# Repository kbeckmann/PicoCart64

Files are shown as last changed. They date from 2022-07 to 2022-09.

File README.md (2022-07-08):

# PicoCart64

Nintendo 64 flash cart using a Raspberry Pi RP2040

Join the Discord server to participate in the discussion and development of this project.

Join the Discord! (https://discord.gg/2Gb3jWqqja)

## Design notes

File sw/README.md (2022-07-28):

To build and flash with a j-link:

```bash

# First of all, don't forget to update submodules
git submodule update --init

# If you have more than 2MB flash, you need to change the SDK file src/rp2_common/pico_standard_link/memmap_copy_to_ram.ld (for now!):
# Change to: `FLASH(rx) : ORIGIN = 0x10000000, LENGTH = 16384k`

cd sw

# Load a rom into sw/picocart64/rom.h
# `--compress` will compress the rom with a simple compression scheme.
./scripts/load_rom.py --compress my_rom.z64

mkdir build
cd build

# Configure cmake. To use NTSC, set -DREGION=NTSC
# If you have more than 2MB flash, you need to change the flash size by adding -DFLASH_SIZE_MB={one of 2,4,8,16} here.

cmake -DREGION=PAL ..

# Build
make

# You can now flash it by holding down the BOOT button and resetting the device, then mounting the usb mass storage device, then copy the file picocart64/picocart64.uf2 to the mounted path and run `sync`.

# Alternatively, you can use openocd with a J-Link:

# Requires https://github.com/raspberrypi/openocd
# AUR package if you're on archlinux: https://aur.archlinux.org/packages/openocd-raspberrypi-git
openocd -f interface/jlink.cfg -c "transport select swd; adapter_khz 1000" -f target/rp2040.cfg -c "program ./picocart64/picocart64.elf verify reset exit"

# Note! You *have* to power reset the pico after flashing it with a jlink, otherwise multicore doesn't work properly.
# Alternatively, attach a debugger, `mon reset halt`, `c`, does the trick as well. It seems that openocd's `reset run` doesn't work properly.

```

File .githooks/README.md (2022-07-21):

# .githooks

To install the git hooks, please run `git config core.hooksPath .githooks` from the root of the repository.

### `pre-commit`

Executes `./sw/scripts/indent.sh -c` before a commit is made. If indentation was fixed, this will be changed in your working copy, i.e. you have to manually review and stage the changes before committing again.

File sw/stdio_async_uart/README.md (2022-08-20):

# stdio_async_uart

This is a simple interrupt based asynchronous UART TX module that works as a drop-in replacement for stdio_uart.

It uses a ringbuffer to queue up data that is to be transmitted, and starts by sending one byte.

When the byte has been transmitted, an interrupt is fired, and the next one is sent, until the tail of the ringbuffer has caught up with the head.

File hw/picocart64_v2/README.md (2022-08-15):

# PicoCart64 v2.0

:exclamation: Do not produce PCBs based on this yet, boards are untested! :exclamation:

## Errata

### v2.0
- Less than ideal VBus' routing on Inner Layer 1. The power routing should work and passes DRC, but could be better.

## Changelog

### v2.1-unreleased
- Improved power routing for VBus'

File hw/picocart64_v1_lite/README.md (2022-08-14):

# PicoCart64-lite v1.2

## Errata

### v1.3
- None so far

#### v1.2
- None so far

### v1.1
- None so far

### v1.0
- Bad power routing, thin trace goes to N64_VCC

## Changelog

### v1.3
- Added JP1, a solder bridge to make it possible to use the WeAct RP2040 third party Pico board

### v1.2
- Improved routing a lot, removed many vias
- Added more ground stitching vias
- Functionally equivalent to v1.1 and v1.0

### v1.1

- Improved power routing to N64_VCC

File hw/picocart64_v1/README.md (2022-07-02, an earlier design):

# PicoCart64 v1.0 (full)

## Errata

### v1.0
- Silk screen labels for JP1 - JP4 are in the incorrect order. It goes from bottom to top but should go the other way, i.e. correct mapping is:
  - JP1=S_DAT
  - JP2=SI_CLK
  - JP3=EEP_SDAT
  - JP4=NMI
- The signal EEP_SDAT does not exist, i.e. JP3 is unconnected.
- Pin 44 (INT/interrupt pin) is not broken out. This can be fixed with a bodge wire from pin 44 to JP3 (since EEP_SDAT is not a connected net). Pin 44 is on the top layer which is convenient.

## Changelog

### v1.1

- Connected pin 44 to JP3 (was unconnected earlier, see errata).
- Fixed silkscreen:
  - JP1=S_DAT
  - JP2=SI_CLK
  - JP3=INT
  - JP4=NMI
- Added more ground stitching vias to improve the ground plane.
- Improved routing, removed some vias

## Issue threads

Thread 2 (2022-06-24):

Investigate booting flashless RP2040 from second RP2040 over SSI/XIP -> PIO

kbeckmann, 2022-06-24:
Investigate if it's possible and practical to let one RP2040 (pico1) boot from a second RP2040 (pico2) by connecting the Flash pins to the gpios of the second.

Might need to use PIO to emulate flash in the second RP2040.

Will probably need to lower the flash speed configuration

Implementation idea:

pico2 loads the image it wants to emulate into RAM first.
pico2 sets up PIO to quickly serve QSPI read requests.
Could borrow code/ideas from the PicoCart64 code.

swetland, 2022-07-05:
Luke Wren mentioned (in a twitter conversation) that the bootrom's download of boot2 (256 byte secondary loader) is done at 1MHz and believes even a bit-banging solution should be workable.

Rather than trying to emulate QSPI modes or faster transports, my thinking was to just write a custom boot2 that would use SPI to pull an image into SRAM and jump to it.

For my use cases (using the 2nd RP2040 as an IO expander, etc), running a fixed image that is loaded at boot and fits inside the (generous) 264KB of onboard SRAM would be plenty sufficient.

At 8MHz and using large transfers, SPI download of a 128KB image would probably take under 150ms. (131ms if there were no overhead between transfers and all data were sent back to back)

kbeckmann, 2022-07-05:
Another approach which was discussed in our discord was to physically share one flash chip between the two RP2040 - even less work!

The reset/run pin of MCU1 is pulled low with a resistor, and is also connected to MCU0.

MCU0 boots and loads its program into SRAM. It reads the GPIO connected to MCU1's reset pin and sees a '0' - this lets it know that it is MCU0.

MCU0 now enables the GPIO, letting MCU1 boot. When MCU1 has booted and loaded its program into SRAM, it reads the same GPIO pin, but we make sure to connect it to a net that is pulled high in idle - now it knows it is MCU1.

kbeckmann, 2022-07-16:
We have to verify the following:

We probably need to configure the CS line to be open drain and enable a pull-up. Otherwise, when the other rp2040 is idling, it will keep CS=1 which will interfere when the first pico wants to read from the flash.
If that's not possible (because of bootrom etc), the boot sequence probably needs to be like this:

Pico1 boots normally, copies its program to RAM
Pico1 disables its SSI interface, ensuring that CS line becomes high impedance / disable output
Pico1 pulls Pico2_RUN low, allowing Pico2 to boot
Pico2 can now assert FLASH_CS high or low without any issue.
Pico2 disables its SSI interface

FLASH_CS is now allowed to be asserted by either Pico, high or low.

kbeckmann, 2022-07-24:
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

Proof of concept works!

```c

/**
 * SPDX-License-Identifier: BSD-2-Clause
 *
 * Copyright (c) 2022 Konrad Beckmann
 */

#include <stdio.h>
#include "pico/stdlib.h"
#include "hardware/structs/ssi.h"
#include "hardware/structs/ioqspi.h"

int main(void)
{
	int count = 0;

	// GPIO 2 is connected from Pico 0 to the RUN pin of Pico 1
	gpio_init(2);
	gpio_set_dir(2, GPIO_IN);

	// GPIO 25 / LED is a slow signal to show if we are running
	gpio_init(25);
	gpio_set_dir(25, GPIO_OUT);

	int pico_id = gpio_get(2) + 1;
	stdio_init_all();

	sleep_ms(1000);

	// Turn off SSI
	ssi_hw->ssienr = 0;

	// Set all QSPI IOs high impedance (disable OE)
	for (int i = 0; i < 6; i++) {
		ioqspi_hw->io[i].ctrl = (ioqspi_hw->io[i].ctrl & (~IO_QSPI_GPIO_QSPI_SCLK_CTRL_OEOVER_BITS) |
								(IO_QSPI_GPIO_QSPI_SCLK_CTRL_OEOVER_VALUE_DISABLE << IO_QSPI_GPIO_QSPI_SCLK_CTRL_OEOVER_LSB)	);
	}

	sleep_ms(1000);

	if (pico_id == 1) {
		// I am Pico 1, let Pico 2 boot
		gpio_set_dir(2, GPIO_OUT);
		gpio_put(2, 1); // GPIO2 = HIGH
	}

	while (true) {
		count++;
		printf("Hello, world! I am Pico %d -- %d\n", pico_id, count);
		gpio_put(25, !!(count & 1)); // GPIO25 = toggle LED slowly
		sleep_ms(1000);
	}
	return 0;
}

```

Closed 2022-07-24.

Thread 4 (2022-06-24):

Implement ESP32-C3 firmware update

kbeckmann, 2022-06-24:
Write/port code that updates the ESP32-C3 WiFi module over UART and toggles the boot/reset pins, from an rp2040.

See https://github.com/espressif/esp-serial-flasher

kbeckmann, 2022-06-29:
After reviewing the third v2 concept, using SPI for both communication and firmware update seems to be the way to go (same pins and more reliable probably).

kbeckmann, 2022-08-04:
Connect wires to the module so that:
GPIO2 has a pull-up
GPIO8 has a pull-up
GPIO9 is controllable from MCU2.
EN has pull-down and is controllable from MCU2. (force it to *not* boot until MCU2 says so)

Connect MCU2 UART peripheral pins to ESP32 UART.

See https://www.espressif.com/sites/default/files/documentation/esp32-c3-wroom-02_datasheet_en.pdf for details

Closed 2023-12-08.

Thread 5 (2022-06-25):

Design SPI protocol between MCU1 and MCU2

kbeckmann, 2022-06-25:
In the v2 concepts we need pico1 (connected to the n64 bus) to load/send:
- sram data
- wifi data
- sdcard data
- debug data
- etc...

via MCU2.

Start prototyping on a communication solution for this.

kbeckmann, 2022-08-20:
Look at src/rp2_common/cyw43_driver/cyw43_bus_pio_spi.c + cyw43_bus_pio_spi.pio for SPIO with a shared MISO/MOSI pin.

Closed 2023-12-08.

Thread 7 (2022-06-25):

Prepare firmware for the ESP32-C3

kbeckmann, 2022-06-25:
Prepare some kind of firmware for the ESP32-C3 so it can be used as a WiFi peripheral.

Most promising path seems to be to run https://github.com/adafruit/nina-fw on the ESP32-C3, and https://github.com/adafruit/WiFiNINA on the RP2040.

Ensure that it can be programmed by #4

kbeckmann, 2022-08-04:
See https://github.com/espressif/esp32c3-direct-boot-example for a simple project setup

kbeckmann, 2022-08-04:
Might fork https://github.com/espressif/esp-at and configure it to our needs?

kbeckmann, 2022-08-17:
Or maybe https://github.com/arduino/nina-fw

kbeckmann, 2022-08-17:
https://github.com/adafruit/nina-fw

kbeckmann, 2022-08-17:
https://github.com/adafruit/WiFiNINA/

zzzbatmand, 2022-11-14:
Any progress with nina-fw on the ESP32-C3?

Closed 2023-12-08.

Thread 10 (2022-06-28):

Implement and evaluate Pico<->Pico performance over QSPI

kbeckmann, 2022-06-28:
Since the Pico isn't an FPGA, it will be hard to latch data on a rising/falling edge of a clock, so we probably can't run it at system clock on the receiving side.

Investigate the limitations around this and what bandwidth we can reach using 4 data pins and 1 clock.

kbeckmann, 2022-06-28:
Relates to #5

kbeckmann, 2022-06-29:
Could also try DDR, there's nothing really stopping us from that. But we're limited to at most sys_clk/2 anyway I suppose. We probably need to go down to sys_clk/4 in order to have some margin.

kbeckmann, 2022-07-10:
Might want to investigate if the SSI peripheral can be used for this.

If going the route where one flash chip is connected to two RP2040s, the both chips will already be connected without sacrificing any pins (might need one CS pin though).

kbeckmann, 2022-07-25:
Seems problematic. See branch https://github.com/kbeckmann/PicoCart64/tree/ssi-experiments

Implementing a SSI/QSPI slave device seems to not be possible due to missing pin muxing.

`ss_in_n` is hard-tied high, but it's needed for: `slave select input to the DW_apb_ssi slave`. My understanding is that this means that we cannot implement the slave mode with the IP block.

What we should be able to do is to bitbang a slave device. Initial tests show that the SCLK pin can't be properly sampled for some reason. Output bit banging in a tight loop caps out at around 36ns if we toggle the pin in a tight loop. Not ideal.

Conclusion so far: Might be better of with a custom SPI implementation with PIO.

kbeckmann, 2022-08-10:
Conclusion: Going for PIO+SPI for pico-pico communication. PIO in order to save one pin (combining mosi and miso).

Closed 2022-08-10.

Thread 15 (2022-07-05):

Integrate FreeRTOS

kbeckmann, 2022-07-05:
We need an RTOS to run CIC emulation and EEPROM + FlashRAM emulation on the same core.

Investigate if there is a FreeRTOS port for RP2040 out there already, otherwise port it.

gcochard, 2022-07-05:
There's a ChibiOS port for the rp2040 which could be viable: https://forums.raspberrypi.com/viewtopic.php?t=308510

kbeckmann, 2022-07-05:
Thanks! I haven't looked closer at ChibiOS. How does it compare to FreeRTOS feature wise? I think we mostly only need some sort of scheduler that runs on one of the cores that lets us run multiple tasks in parallel with preemption. We probably don't "proper" multicore support, since the core that handles the N64 PI interface has absurdly high latency requirements, so it will be fully busy with that.

kbeckmann, 2022-07-10:
Just noticed that the pico_w examples include a FreeRTOS integration too: https://github.com/raspberrypi/pico-examples/blob/master/pico_w/freertos/CMakeLists.txt

kbeckmann, 2022-07-10:
Integrated FreeRTOS now.

Closed 2022-07-10.

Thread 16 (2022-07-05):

Optimize SRAM access

kbeckmann, 2022-07-05:
Currently it's too slow except for homebrew or patched roms.

Closed 2022-07-05.

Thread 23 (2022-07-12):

[WiFi] Add server solution to push out ROMs to carts

kbeckmann, 2022-07-12:
Let the cart connect to the user's wifi, then connect to a server (either local or on the internet maybe?), then let the user control the server to push out a ROM file on demand.

clktmr, 2023-10-02:
Will it be possible to access the Wifi module from the ROM?

kbeckmann, 2023-10-02:
As of now, v2 is scrapped. I'm working on adding wifi support to v1 lite with a pico-w. It should be possible yes but there is no API yet.

clktmr, 2023-10-03:
Will the Picos SPI be memory mapped on the PI bus? Or how will this work?

kbeckmann, 2023-10-03:
Yes this is how it works today - the N64 binary / ROM is stored on the pico's external spi flash. When there are PI read requests in the ROM address range, it will load data from the external flash (with or without compression). See https://github.com/kbeckmann/PicoCart64/blob/develop/sw/picocart64_v1/n64_pi_task.c#L91-L118

Closed 2023-12-08.

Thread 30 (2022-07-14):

Design a v2 PCB before 20th July

kbeckmann, 2022-07-14:
I want to have physical boards when my vacation starts.

kbeckmann, 2022-07-14:
Might do multiple boards with different ways that everything is hooked up.

PCBs are cheap, delivery is not. Multiple orders cost more and take longer time. Better to do multiple boards and order at the same time.

Closed 2022-08-20.

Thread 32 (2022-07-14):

Investigate Pin 44,  /INT1

kbeckmann, 2022-07-14:
Can we use this to run arbitrary code from closed source ROMs without patching?

What do we need to patch in order to jump to our memory area?

Can we extract screenshots from the frame buffer directly?

Possible to debug?

Read/write memory, and continue?

kbeckmann, 2022-07-15:
See https://github.com/DragonMinded/libdragon/pull/291 for interrupt handling

kbeckmann, 2022-07-15:
Some good info and ideas from Rasky:

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

Closed 2024-04-23.

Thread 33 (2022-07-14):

Ignore PI accesses properly

kbeckmann, 2022-07-14:
Currently the code expects us to handle all PI read and write requests. If we don't, the state machine ends up in a bad state.

Example: User has a physical N64DD connected which will respond to certain memory accesses. If we also respond, there will be a bus conflict.

Solve this by e.g. resetting the state machine in the else case in the big while/if chain in n64_pi.c

How to test? Not sure, don't have a N64DD,

Closed 2022-07-15.

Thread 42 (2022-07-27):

PicoCart64-lite v1: Add solder bridge jumper to support WeAct RP2040 pinout

kbeckmann, 2022-07-27:
The official Raspberry Pi Pico pinout has 3V3 on pin 36. 3V3_EN is on pin 37, and is connected to VSYS (5V/VUSB) through a 100K resistor.

On the WeAct RP2040 boards, Pin 36 is GPIO29, and 37 is 3V3. This means that the pins 36 and 37 need to be connected together. However, this must _not_ be done on the official Pico boards.

Add a solder bridge jumper to do this easily, but add a clear warning/explanation so people don't bridge this by mistake.

kbeckmann, 2022-08-14:
Solved in PicoCart64-lite v1.3

Closed 2022-08-14.

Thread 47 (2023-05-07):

can't run testrom

hpx1984, 2023-05-07:
Hi Sir

built one lite ,can boot to the menu but can't run testROM(there has one fail item)
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
pressed all button and no action
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

My step as below, please help me for improve it, many thanks Sir
1. programmed picocart64-v1-ntsc.uf2
2. Created testrom.uf2
3. programmed testrom.uf2

kbeckmann, 2023-05-07:
You have successfully booted the test rom actually. The failed test is a persistent SRAM test - if you press the reset button it will pass.

The menu is just a mock menu. It doesn’t do anything.

hpx1984, 2023-05-07:
many thanks your quickly replied ,Sir

is it meets this lite version still can't run any ROMs or just can run the ROMs which show in the mock menu ?

i want to buy a Weact Board if it can support to run the ROM

kbeckmann, 2023-05-07:
Follow the steps in https://github.com/kbeckmann/PicoCart64/blob/develop/sw/README.md or use https://picoc.art to change the rom

hpx1984, 2023-05-08:
thank you so much ,sir
My 16m board will arrive end of this week, so happy time on your project, so great project

Closed 2023-05-07.

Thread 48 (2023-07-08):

[question] Could you connect more SPI devices to the QSPI boot flash bus?

JensRestemeier, 2023-07-08:
I was wondering, if you run the code from RAM, could you connect more flash or an SD-card to the QSPI pins? You won't have the execute-in-place available, but could store data?
Or is there a hardware/software limitation?

That would free up a few pins for the N64 bus.

dogtopus, 2023-11-24:
You actually can and it has been done before IIRC. Although bank-switching like this tends to be expensive latency-wise and console that use the flashcart are usually very picky about any sorts of latencies.

JensRestemeier, 2023-11-25:
Thanks, I was expecting that only some kind of menu (or homebrew) would access those extra devices, and could avoid cartridge access while those devices are mapped in.

Closed 2023-11-25.

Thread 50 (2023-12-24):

Add Multiple License Files

MasonStooksbury, 2023-12-24:
Hello there! I noticed that this repo has two licenses on it. Not sure if you knew, but GitHub made it so that you can upload several license files and it will show them without issue on the right hand side. Here is an example from one of my repos (https://github.com/MasonStooksbury/Hex-Clock)

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

<br><br>

The badges you see in my README can be added using this text:

`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`

`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`

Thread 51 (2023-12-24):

Compatipel with that pico?

Liriel-666, 2023-12-24:
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
Is the lite version of the board compatible with that pico 2040?

kbeckmann, 2023-12-25:
No, not without modifications. Notice the pins vin and vout, and compare with the original or weact pico board.

Liriel-666, 2023-12-25:
is Vin and Vout the only difference?
sry i am not that big in the pico thing and for me the rest looks good

Liriel-666, 2023-12-25:
to what i can see the pinout ist most the same to the non weact pico.
i see some difference  in the last 10 pins but i dont now how to fix it.
What pin of the lite  1.4 board must connect to what pin on the black pico board?

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

curcius, 2024-01-17:
Were you able to use this card? I bought the same one and did all the soldering points but it doesn't generate an image on the N64 =[

ppattss, 2024-01-18:
> Updating, I was able to run Homebre as Testrom and a cell phone game converted to UF2, but the Nintendo 64 games don't start at all. I've checked pin by pin and there are no shorts or soldering failures.

It might be related to region-checking and not having the correct one selected when making the UF2 file? or CIC issue?

Did you reconnect VREF to GP29? the VREF jumper isnt connected on the board i got, but is in all the pics of that board.

curcius, 2024-01-18:
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

Thank you for responding, but I've tried everything and neither UF2 NTSC nor PAL M works, I've tested several games and nothing, I've closed and opened the jumper and it gives the same results... I believe it's some incompatibility with the flash, no. I can think of nothing else, the rpi works, I've tested it with other programs like Micropython, but 64 games don't run, just homebrew...

curcius, 2024-01-19:
I managed to solve it, I had to use the 3v3 from the console board directly on the RPI, I was using the RPI's USB power supply and it didn't work, I made the jumper to the 3v3 on the RPI and it worked perfect. Thank you everyone, I hope the project moves forward.
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

Liriel-666, 2024-01-19:
i dont get my to work with a weact pico
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

I solder all correct. because i destroy on unsolderng the other pico i replace the jumper with a cable
al solderpoints are there and correct.
i even solder the debug port

nothing with any uf2 convertet file.
I put firmware on it and then restart it.
then i put the testrom or a game on it and nothing on my pal n64

samowitsch, 2024-07-15:
@Liriel-666 i have the exact same problem as you. I ordered like you a WeAct RP 2040 and nothing is working. Did you solved it in the meantime?

samowitsch, 2024-08-07:
@kbeckmann Neither the WeAct 16MB nor the Bitfunx 16MB Pico board works. Are there any secret tips that aren't mentioned anywhere? Does the picocart64-v1-pal/ntsc.uf2 work with any Flash Ram size?

kbeckmann, 2024-08-08:
> @kbeckmann Neither the WeAct 16MB nor the Bitfunx 16MB Pico board works. Are there any secret tips that aren't mentioned anywhere? Does the picocart64-v1-pal/ntsc.uf2 work with any Flash Ram size?

I'm sorry, I don't know to be honest. WeAct 16MB have been known to work earlier, but it's also possible that the manufacturer changed something, e.g. maybe the flash is not the 133MHz variant or so?

samowitsch, 2024-08-12:
The following "solutions" work for me. (By the way, thanks for the feedback on Discord from be0w0lf710, which pointed me in the right direction. I would never have questioned BSS84 that something is not working properly here.)

**Bitfunx board (100% pin compatible)**
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

**Weact board**
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

reflekt00, 2024-10-22:
@samowitsch has this setup bridging 5V on the weact board to the 3.3V rail been working reliably for you? I'm in the same boat, the cart won't load a rom with the transistor in place.

samowitsch, 2024-10-26:
@reflekt00 it worked for me without the components and just a jumper wire. But with this „workaround“ the USB cable should not be connected when the picocart is plugged into the N64.

Closed 2024-12-15.

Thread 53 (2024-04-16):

20240330 release doesn't work on PAL N64

michalderkacz, 2024-04-16:
Have two N64s: Europe/PAL model and Japan/NTSC model.

The Japan/NTSC model works great with picocart64-v1-ntsc.uf2. Testroom and any game I've flashed so far work fine. Have only a problem with 240pSuite-newer test suite that doesn't work.

The Europe/PAL version doesn't work at all with picocart64-v1-pal.uf2 + testrom (nothing on the screen). It works fine with PAL cartridges.

kbeckmann, 2024-04-17:
That’s odd. I’m developing on a PAL console primarily and this works for me. Potentially there could be a problem with the pico you used for that unit? How’s the soldering etc?

Regarding 240p, this should also work. I have my own test rom but could you let me know where to find yours?

michalderkacz, 2024-04-17:
I use WeAct 16 MB Pico attached to the broken Supper64 cartridge:
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

Test works fine with it:
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

The N64 240p Suite is from  [here](https://twitter.com/240pTest/status/1215673194461515778).

If the last release works on your PAL N64 it's probably a problem with my one. Maybe the connector is slightly misaligned and works with the original cartridges but it doesn't with Super64 one. Will try to check all connections from the Pico to the N64 motherboard.

michalderkacz, 2024-04-18:
The pico definitely works in both consoles:

NTSC
```
PicoCart64 Boot (git rev 2d88074a)
cic_task_entry
second_task_entry
Hello from the N64!
```

PAL
```
PicoCart64 Boot (git rev 2d88074a)
cic_task_entry
second_task_entry
```

I've to disassemble the PAL one...

michalderkacz, 2024-04-19:
So I've disassembled my PAL N64 and started checking the PIF-NUS signals (1996 PIF(P)-NUS 9703 D).

When N64 works (with the original game cartridge) the NMI signal is high. The CIC-DCLK and CIC-DIO signals are as below:

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

In case of the PicoCart I can observe only a short burst of activity on DCLK and DIO, just after power on (I can't catch it on my cheap scope). Next both signals are high and the NMI signal is as below:

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

I checked the continuity of DCLK and DIO directly between the PIF-NUS and Pico pins. It's OK. I also observe the same waveforms on the both sides.

It seems the next step is try to debug the communication in software using the UART as a debug output. Any advice?

kbeckmann, 2024-04-20:
I tested the release again on real hardware and it works for me.

It is possible that the flash on the Pico you use for the PAL version is using a type of flash that doesn't handle 133 MHz. It has been seen in the wild that some 3rd party boards use the cheaper variant that only goes to 104 MHz or so, which is a problem.

What you can test with is the 133MHz variants from the unstable branch. The 133 MHz name is referring to the system clock, i.e. it is not overclocked. So the flash access is running at 133/2 MHz so it mitigates this issue. https://github.com/kbeckmann/PicoCart64/actions/runs/8156039367

michalderkacz, 2024-04-20:
Just tested `picocart64-v1-ntsc-133MHz.uf2` on the NTSC N64 and `picocart64-v1-pal-133MHz.uf2` on the PAL one. The same result: NTSC works, PAL doesn't.

I think I've to try insert some debug prints here and there in the CIC code to see differences in both cases.

kbeckmann, 2024-04-21:
How odd, I haven’t heard of anyone else having exactly this issue. Just for testing, could you try the ntsc firmware on the pal console?

michalderkacz, 2024-04-21:
Tested all possible combinations (NTSC/PAL firmware, NTSC/PAL games).

I think there is something wrong with my PAL console that doesn't reveals in case of the original PAL games (unfortunately have only two of them).  I've replaced all electrolytic capacitors on both consoles, so it shouldn't be a bad capacitor. If it's a problem with some voltage, it's on the edge, so the difference between the original cartridge and  the PicoCart is enough to revel it.

As the communication between PIF and CIC seems to be affected, I want to see what Pico sees from the PIF and when the communication stops. If the problem is there a better scope will probably help to understand it.

The simplest way to handle this problem is probably to buy another PAL N64 but for now I still want to understand this problem instead sweep it under the rug.

kbeckmann, 2024-04-21:
The CIC data transfer rate is very slow so even with a slow scope you should be able to capture this fine.

The related code is here https://github.com/kbeckmann/PicoCart64/blob/develop/sw/n64_cic/n64_cic.c

You can print using printf, but if you want to be sure it doesn't affect timing you can use uart_print_hex_u32 which is very fast. It's non-blocking and prepares the string in a relatively fast way.

Still I think it's odd that you are experiencing this issue, can't wrap my head around it. My gut feeling is that you might be getting bit errors over the wire which then causes the crc to be incorrect so the PIF rejects it.

Try to lower the bus speed. You can do so easily by editing the start of the ROM.

´´´

	// SDK default, 0x80371240
	//                  DCBBAA
	// AA = LAT
	// BB = PWD
	//  C = PGS
	//  D = RLS
	//
	// 1 cycle = 1/62.5 MHz = 16ns
	// Time = (register+1)*16ns
	// LAT = tL = 0x40 = 65 cycles
	// PWM = tP = 0x12 = 19 cycles
	// PGS      = 0x07 = 512 bytes page size
	// RLS = tR = 0x03 = 4 cycles
´´´

Also, if you end up compiling your own pico formware, you have to use at least gcc 12.x IIRC. Older versions will not optimize the code enough.

michalderkacz, 2024-04-24:
Managed to compile the PicoCart using arm-gnu-toolchain-12.3.rel1.

Added some  debug prints:

```c
	cic_write_id(region);
	stdio_uart_out_chars("write_id\r\n", 10);

	// hw_tim_setup(TIM_ID_CIC, 500, cic_write_id_failed);

	cic_write_seed();
	stdio_uart_out_chars("write_seed\r\n", 12);
	// hw_tim_stop(TIM_ID_CIC);

	cic_write_checksum();
	stdio_uart_out_chars("write_checksum\r\n", 16);
	cic_init_ram(region);
	stdio_uart_out_chars("init_ram\r\n", 10);

	uint32_t iter = 0;
	while (1) {
		uint8_t cmd = 0;
		cmd |= (cic_read() << 1);
		cmd |= cic_read();
		uart_print_hex_u32(iter++);

		switch (cmd) {
		case 0:{
				stdio_uart_out_chars("compare_mode\r\n", 14);
				cic_compare_mode(region);
				break;
			}

		case 2:{
				stdio_uart_out_chars("x105_mode\r\n", 11);
				cic_x105_mode();
				break;
			}

		case 3:{
				stdio_uart_out_chars("reset_cb\r\n", 10);
				cic_soft_reset(cic_reset_cb);
				break;
			}

		case 1:
		default:{
				stdio_uart_out_chars("default\r\n", 9);
				while (1) {
					vPortYield();
				}
				break;
			}
		}
	}
```

NTSC
```
PicoCart64 Boot (git rev 2d88074a)
cic_task_entry
second_task_entry
write_id
write_seed
write_checksum
init_ram
00000000
compare_mode
00000001
compare_mode
00000002
compare_mode
00000003
compare_mode
00000004
compare_mode
00000005
compare_mode
00000006
compare_mode
00000007
compare_mode
00000008
compare_mode
00000009
compare_mode
0000000A
compare_mode
0000000B
compare_mode
0000000C
compare_mode
0000000D
compare_mode
0000000E
compare_mode
0000000F
compare_mode
00000010
compare_mode
00000011
compare_mode
00000012
compare_mode
00000013
compare_mode
00000014
compare_mode
00000015
compare_mode
00000016
compare_mode
00000017
compare_mode
00000018
compare_mode
00000019
compare_mode
0000001A
compare_mode
0000001B
compare_mode
0000001C
compare_mode
0000001D
compare_mode
0000001E
compare_mode
0000001F
compare_mode
00000020
compare_mode
00000021
compare_mode
Hello from the N64!
00000022
compare_mode
00000023
compare_mode
...
```

PAL
```
PicoCart64 Boot (git rev 2d88074a)
cic_task_entry
second_task_entry
write_id
write_seed
write_checksum
init_ram
```
Both working PAL cartridges use the same PIF-NUS-7101.

michalderkacz, 2024-05-08:
Before delving further into this issue, I wanted to be able to test with another PAL console.

Eventually tested my PicoCart with another two consoles PAL and NTSC, so for now it had the opportunity to work with two PAL ones and two NTSC ones.

My PicoCart works with both NTSC N64s and doesn't work with both PAL ones.

It seems that PAL consoles doesn't like my DIY cart. I think it's probably an electrical problem (noise, etc.). I'll keep investigate this further in my free time.

kbeckmann, 2024-05-08:
I’m sorry I don’t know. It should work fine if you use a picocart v1 lite PCB with one of the supported pico boards and clones (weact 16MB is confirmed to work fine).

kbeckmann, 2024-05-08:
Before I close this, did you try to lower the bus speed? It's easily done by increasing the values in the rom. E.g. changing 0x80371240 into 0x8037FF40 or something.

michalderkacz, 2024-05-14:
After changing 12 to FF the testrom stared first time but reported an error (red bar, unfortunately restarted it too fast to see something more). Next three or more times didn't started at all and after that it stared starting every time. The RNG stress test runs noticeably slower.

Next I tested it with another PAL console. Didn't start at all.

Flashed the original testrom and now it also runs every time (RNG stress test runs fast) on one of PAL N64 and, of course itdoesn't start on another one.  Now I've one PAL console that works with my Picocart and one that doesn't. There is definitely a progress ;-)

I think you can close this issue because it's probably an electrical problem with my DIY picocart (noise, unmatched impedances, etc.).

But can you check if the 240p test suite works for you: https://twitter.com/240pTest/status/1215673194461515778 (the
240pSuite-newer.z64 one). It's very useful tool and I can't run it on both NTSC and PAL consoles. If you are interested in its source code you can find it here: https://github.com/ArtemioUrbina/240pTestSuite/tree/master/240psuite/N64

kbeckmann, 2024-05-14:
I'll have a look at the 240psuite, doesn't feel right that it doesn't work, so thanks for reporting that! 🙂

Yeah, it sounds like an electrical issue with your problems here. Recommend getting a PCB and soldering a pico onto it, as it improves the signal integrity.

Closed 2024-05-14.

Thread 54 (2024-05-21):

USB Debug functionality

markusbkk, 2024-05-21:
Curious.

Are there any plans to add the ability to stream data straight to the cartridge over the USB port while everything is plugged in and the console is running?

Would be a boon for homebrew devs looking for a cheap USB devcart.

Carl-Llewellyn, 2025-03-29:
This is possible by setting up the USB device in main() using stdio_init_all() after overclocking, then printf can be used to print to USB.

Then if you write to the PC64_REGISTER_UART_TX from the ROM/N64 and replace the stdio_uart_out_chars() with printf() it will come in over the USB instead of UART.

Not sure about writing to N64 memory at the mo.

Carl-Llewellyn, 2025-03-31:
To write to N64 memory:

Set up some buffers:

```
static uint8_t __attribute__((aligned(16))) usb_buffer[USB_BUFFER_SIZE] = {0};
uint32_t usb_bytes_received = 0;
uint32_t read_word = 0;
```

Set up a usb task with FreeRTOS:

```
void usb_task_entry(void *pvParameters) {

  while (true) {
    while (!tud_cdc_connected()) {
      vTaskDelay(pdMS_TO_TICKS(100));
    }

    if (tud_cdc_available()) {
        usb_bytes_received = tud_cdc_read(usb_buffer, USB_BUFFER_SIZE);
		if (usb_bytes_received >= sizeof(uint32_t)) {
 		   read_word = *(uint32_t *)usb_buffer;
		}
    }

    vTaskDelay(pdMS_TO_TICKS(10));
  }
}
```

Add a USB RX register:

```
#define PC64_REGISTER_UART_RX 0x00000010
```

Add the register to this switch and then read it into next_word:

```
          switch (last_addr - PC64_CIBASE_ADDRESS_START) {
          case PC64_REGISTER_MAGIC:
            next_word = PC64_MAGIC;
            break;
          case PC64_REGISTER_FLASH_JEDEC_ID:
            next_word = g_flash_jedec_id;
            break;
          case PC64_REGISTER_UART_RX:
            next_word = read_word;
            break;
          default:
            printf("DEFAULT");
            next_word = 0;
          }
```

Should be good to go.

I'll probably make a fork for this but wont maintain it as I'll just be using it for a project of my own. Lmk and I'll link it here if I do it!

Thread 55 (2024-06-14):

Stackypi support

Tom-Neverwinter, 2024-06-14:
I was randomly looking at rpi2040 boards and noticed this newish one

64MB vs the 16MB

I'm assuming if the pinout is the same it could be flashed with a larger u2f file and work the same?

https://www.kickstarter.com/projects/ash-kumar/pico-zero-rp2040-pico-based-board-on-pi-zero-form-factor

kbeckmann, 2024-06-14:
The root issue is access time to read from the flash, it has to be very fast. The flash controller in the rp2040 has a limit on 16MB. Not sure how this Kickstarter project is doing to solve the issue.

This fork explores a way around this limitation https://github.com/pdaxrom/N64cart

jshield, 2024-06-14:
@Tom-Neverwinter it is not meant to be brother, despite what it says. the Stacky Pi ships with 64Mbit of memory which is 8MiB

kbeckmann, 2024-06-14:
Ah yeah it’s unfortunate that this mistake happens over and over again, bit vs byte. Let’s hope that the next RP chip solves this issue.

kbeckmann, 2024-06-14:
The flash chip vendors usually use bits in their product descriptions and model names like this one https://www.winbond.com/hq/product/code-storage-flash-memory/serial-nor-flash/?__locale=en&partNo=W25Q128JV

Closed 2024-06-14.

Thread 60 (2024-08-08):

new pi pico boards: SparkFun Pro Micro RP2350

Tom-Neverwinter, 2024-08-08:
https://www.youtube.com/watch?v=UnIa2jbEHRk
SparkFun Pro Micro RP2350

The RP3250 is a unique dual-core microcontroller with two ARM® Cortex® M33 processors and two Hazard3 RISC-V processors, all running at up to 150 MHz! Now, this doesn't mean the RP2350 is a quad-core microcontroller. Instead, users can select which two processors to run on boot instead. You can run two processors of the same type or one of each. The RP2350 also features 520kB SRAM in ten banks, a host of peripherals including two UARTs, two SPI and two I2C controllers, and a USB 1.1 controller for host and device support.

The Pro Micro also includes two expanded memory options: 16MB of external Flash and 8MB PSRAM connected to the RP2350's QSPI controller. The RP2350 Pro Micro works with C/C++ using the Pico SDK and MicroPython development environments.

kbeckmann, 2024-08-08:
RP2350/RP2354 sure is an interesting chip! Will keep an eye on it.

It doesn't seem to solve the 16MByte limit (it does support having two separate 16 MB QSPI chips though, but 64MByte seems to not be supported out of the box).

Closed 2024-12-15.

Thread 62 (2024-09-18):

Not Work (N64 - Revision 03)

xmarciox, 2024-09-18:
I used an F-1 World Grand Prix cartridge as a donation and only kept the 4kb save chip.
However, there is no signal in the game, I have already tested all the contacts on the cartridge, there are no broken tracks, I have recorded the firmware several times and nothing, not even the test ROM works.

What could I be doing wrong?

My Nintendo 64 board model is 03.
I've already tried powering directly via the USB-C peak and nothing either.

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

kbeckmann, 2024-09-18:
> not even the test ROM works

Start there and get the test rom to work first. Check your soldering and signal integrity.

xmarciox, 2024-09-18:
> > not even the test ROM works
>
> Start there and get the test rom to work first. Check your soldering and signal integrity.

I tried running the test rom several times and was unsuccessful.
I measured each point from the peak to the plate pad and they are all ok. I spent several hours trying and nothing.
Not what could be wrong.

kbeckmann, 2024-12-15:
I updated the build environment and made stable releases end of October, please try with those. If those don’t work, the root cause is probably a hardware problem.

Carl-Llewellyn, 2025-03-29:
I've done the same and it works fine for me (didn't realise anyone else was doing this janky set up haha!).

I've found that if you're grounding is loose it doesn't like to work, or it works very intermittently. So, worth a go if you are sure you're hooked up correctly.

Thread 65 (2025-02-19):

Only the test ROM works

Carl-Llewellyn, 2025-02-19:
Great project!

I have managed to get the test rom to work with my WeAct 16mb pico.

It works using the stable release and using the uf2 compiler:

https://kbeckmann.github.io/PicoCart64/

I have also compiled from source using the latest develop commit:

https://github.com/kbeckmann/PicoCart64/tree/develop

This works fine with the test ROM. However, _any_ other ROM I try doesn't work.

I have tried SM64, Automobili Lamborghini (2mb), along with some homebrew ([MSK Pong](https://n64squid.com/homebrew/roms/omsk-pong/)) **all** in .z64 converted to uf2.

However, none of these work. Is there meant to be something else I'm meant to be doing? I am currently using the NTFS firmware, then uploading the z64 uf2. For the source I am just using the resulting UF2 that is the firmware and ROM combined.

Carl-Llewellyn, 2025-02-24:
Looks like I was having some CIC issues. Fixed now!

Closed 2025-02-24.

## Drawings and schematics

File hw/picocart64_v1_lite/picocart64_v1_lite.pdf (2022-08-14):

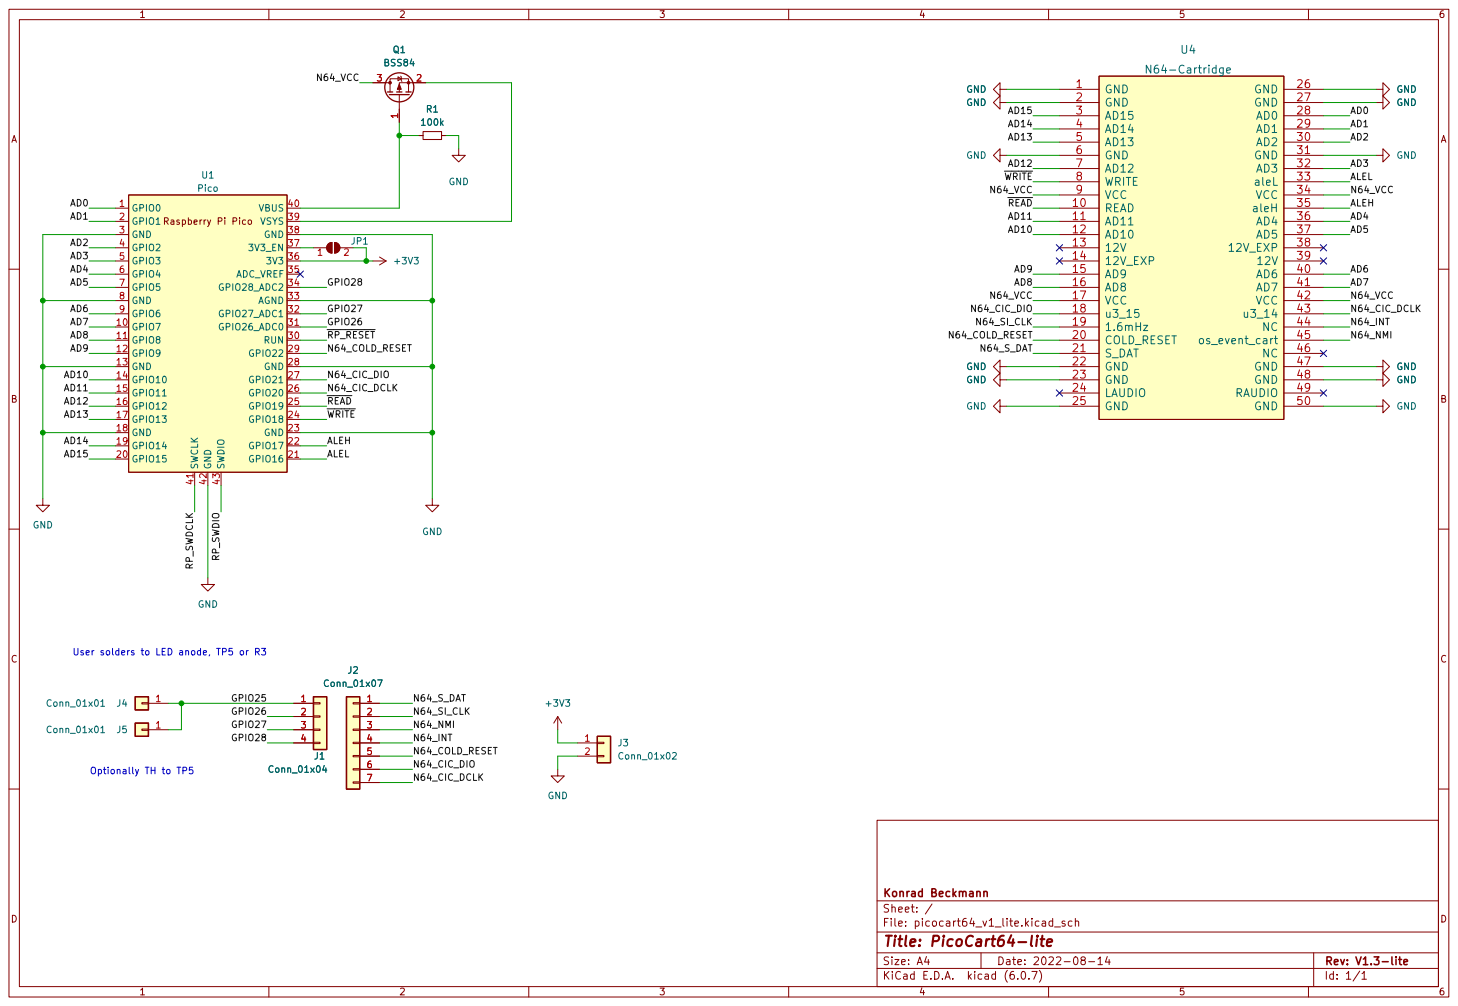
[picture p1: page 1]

File: picocart64_v1_lite.kicad_sch Sheet: / Konrad BeckmannGND

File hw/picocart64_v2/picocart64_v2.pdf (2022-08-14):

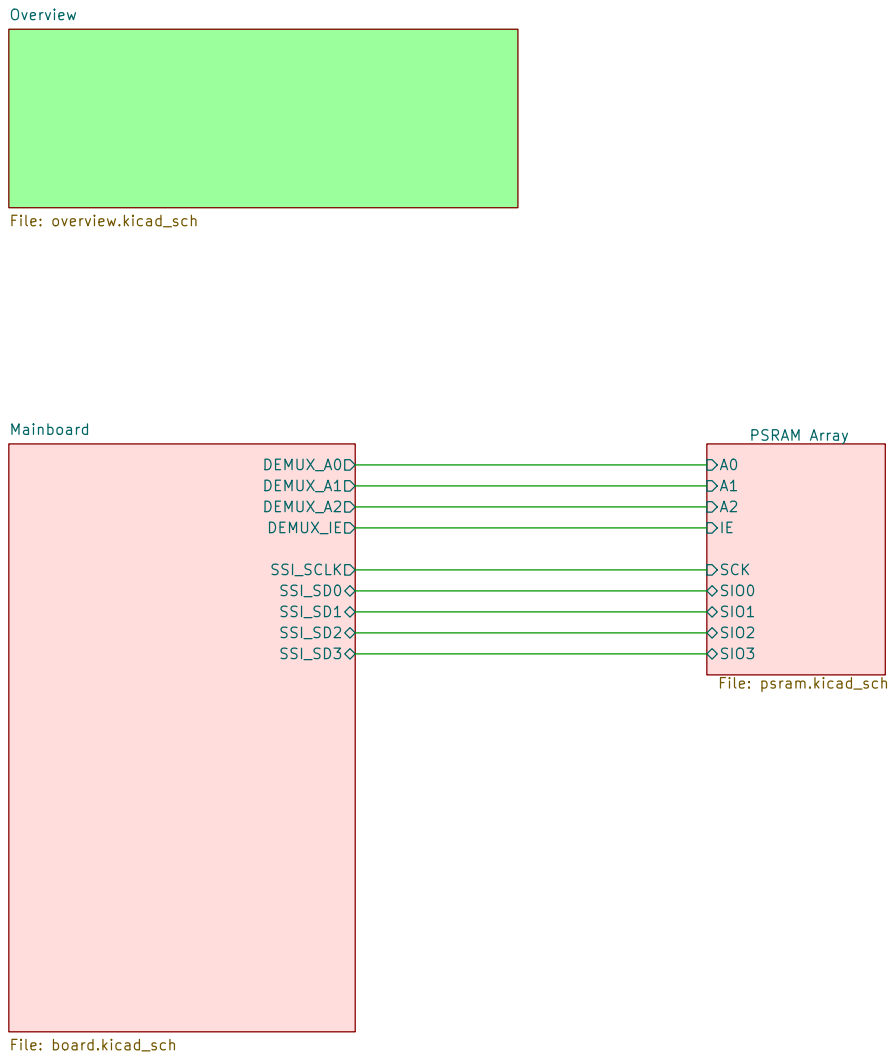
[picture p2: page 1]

File: picocart64_v2.kicad_sch Sheet: / Konrad Beckmann

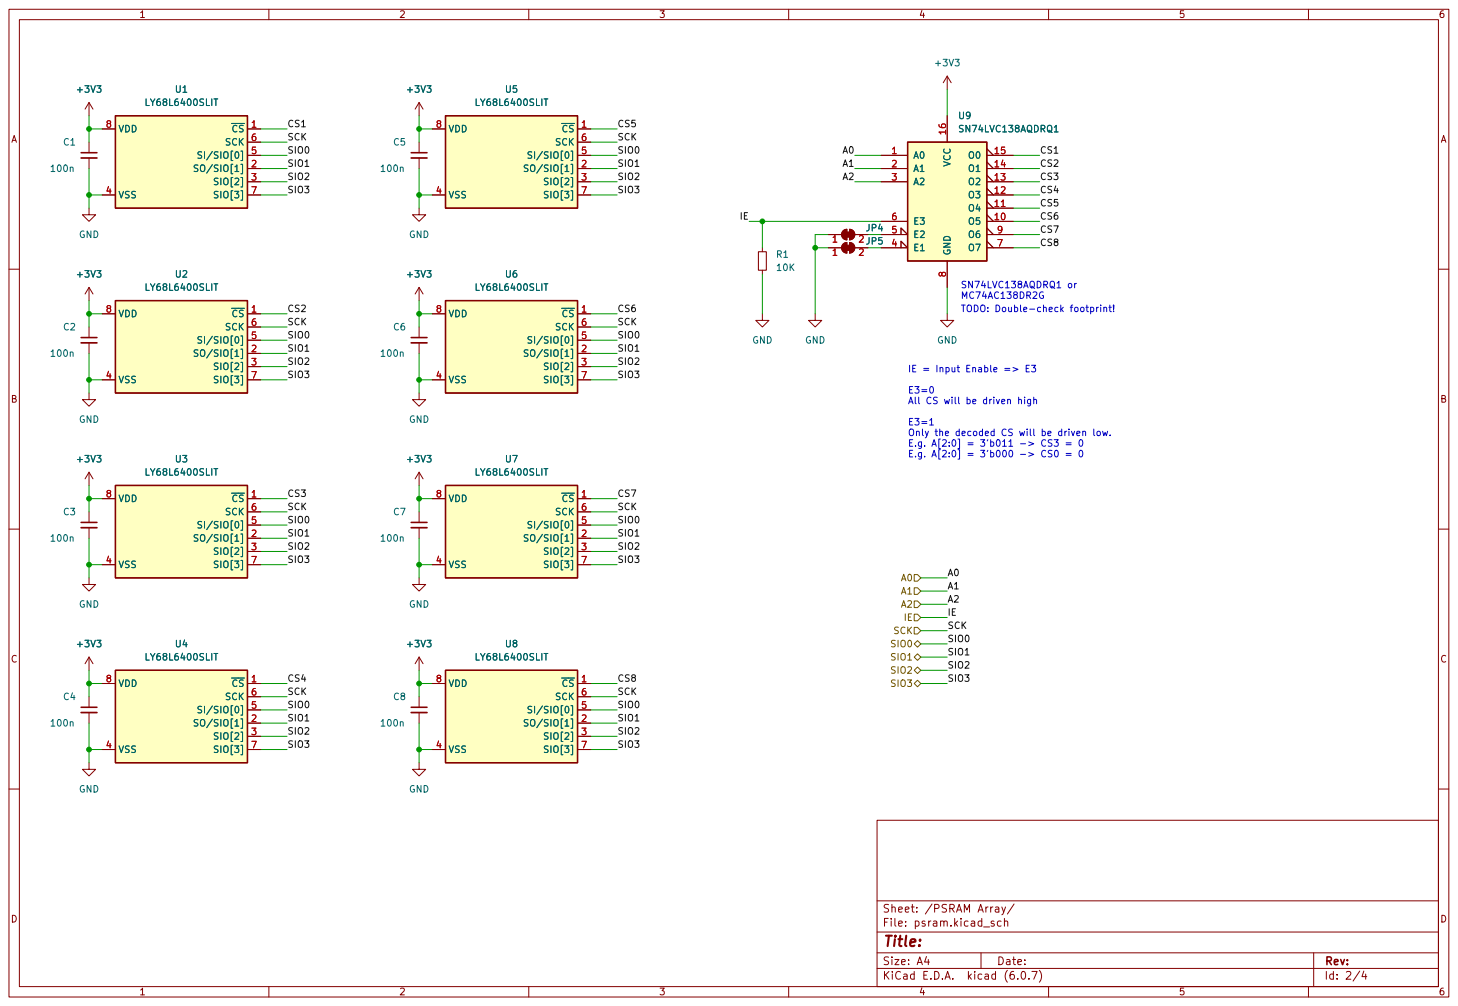
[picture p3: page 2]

IE = Input Enable => E3 E3=0 All CS will be driven high E3=1 Only the decoded CS will be driven low.

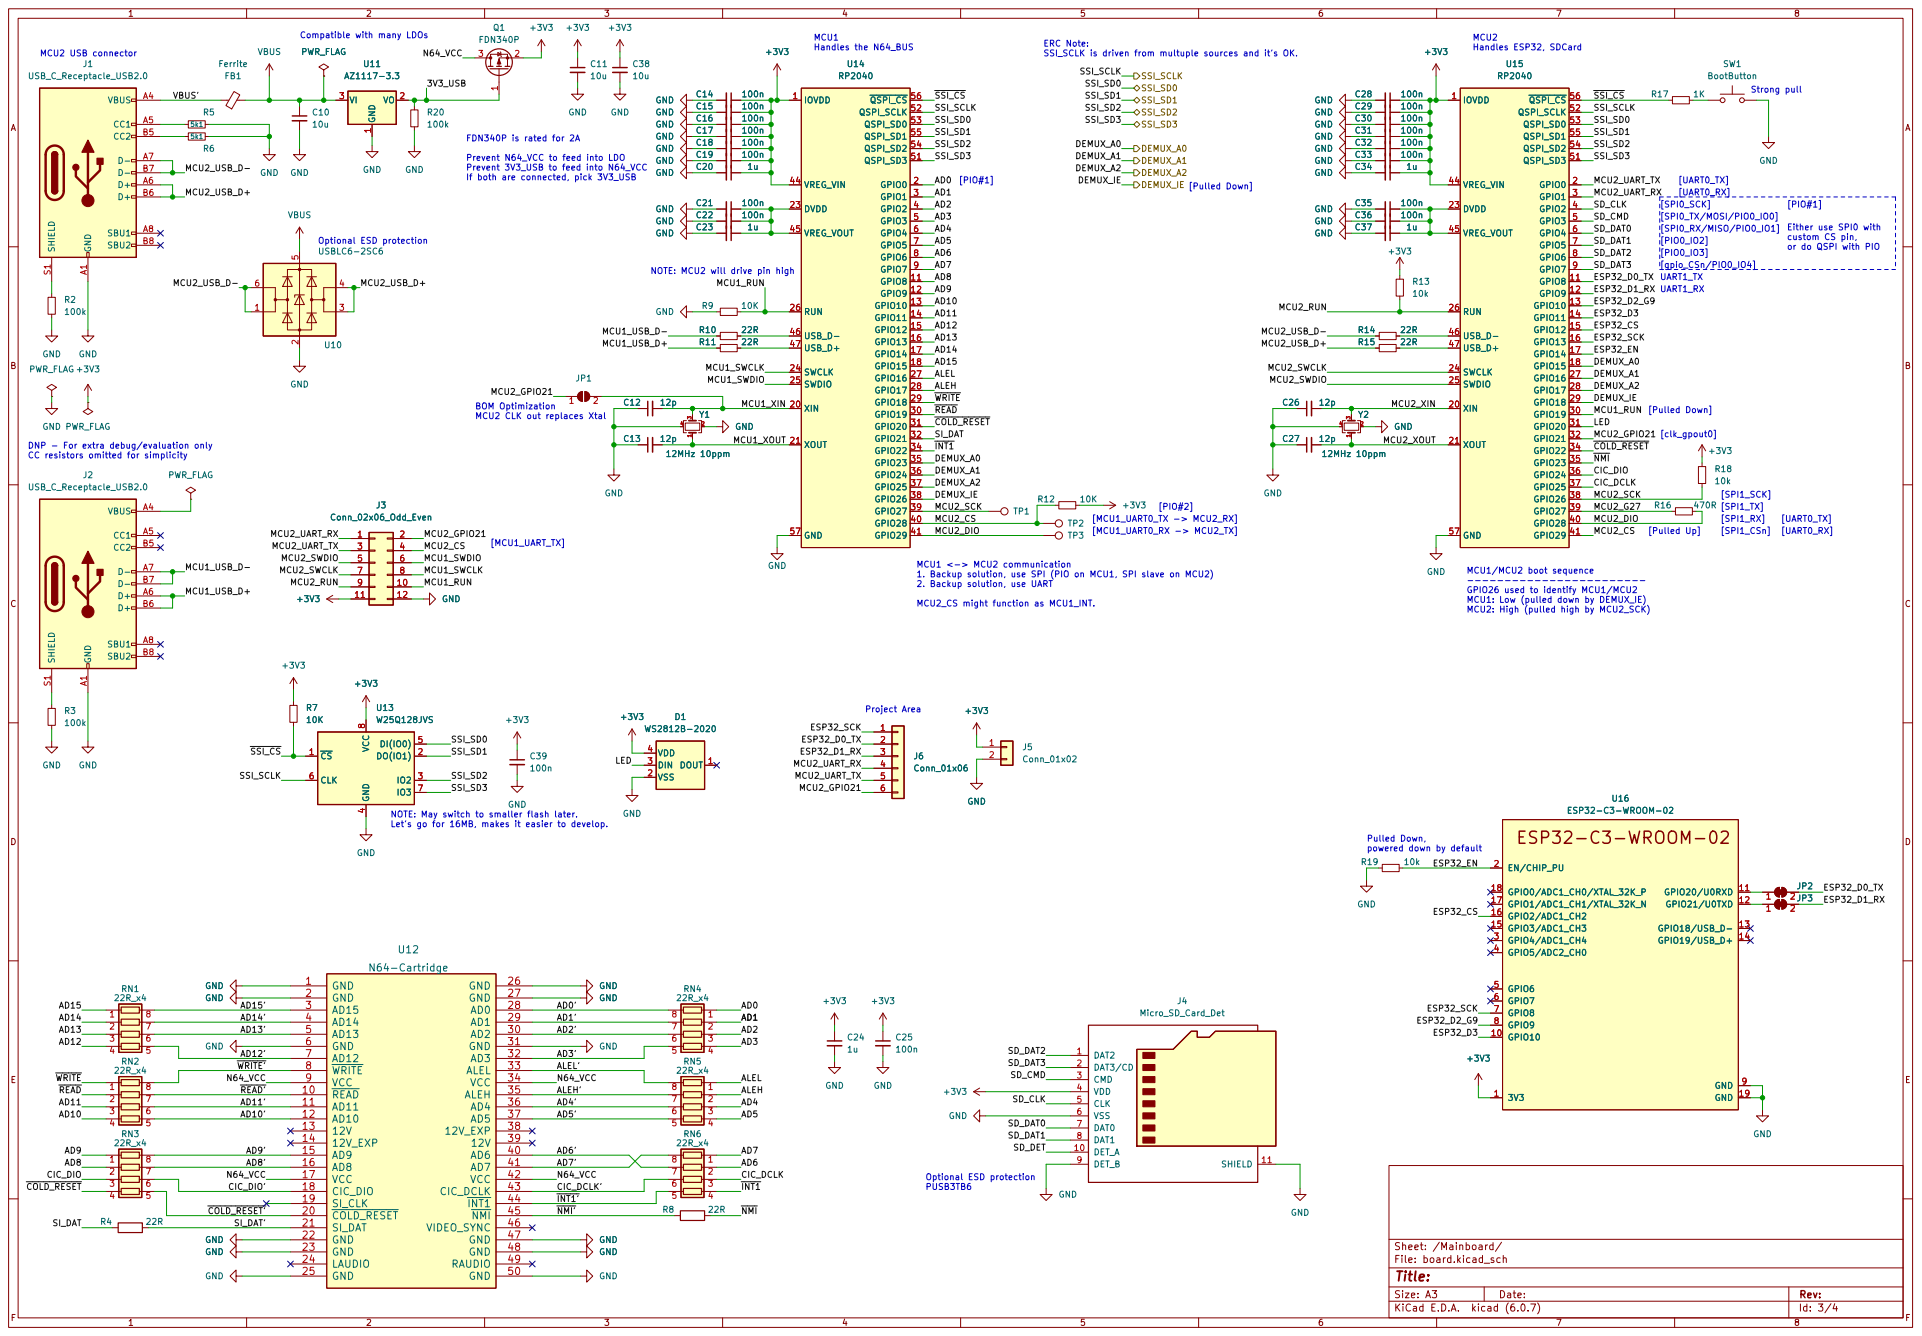
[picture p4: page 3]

Compatible with many LDOs
10u PWR_FLAG

Strong pull MCU1 Handles the N64_BUS

[SPI1_SCK] MCU2 Handles ESP32, SDCard
GND GND

[PIO0_IO3] ERC Note: SSI_SCLK is driven from multuple sources and it's OK.

Prevent N64_VCC to feed into LDO
Prevent 3V3_USB to feed into N64_VCC
If both are connected, pick 3V3_USB

[PIO#1] Either use SPI0 with

custom CS pin, or do QSPI with PIO

NOTE: MCU2 will drive pin high

BOM Optimization
MCU2 CLK out replaces Xtal

GND
DNP - For extra debug/evaluation only
CC resistors omitted for simplicity

J3 Conn_02x06_Odd_Even
10K GND GND GND GND

1. Backup solution, use SPI (PIO on MCU1, SPI slave on MCU2)
2. Backup solution, use UART

MCU1: Low (pulled down by DEMUX_IE)
MCU2: High (pulled high by MCU2_SCK)

NOTE: May switch to smaller flash later.
Let's go for 16MB, makes it easier to develop.

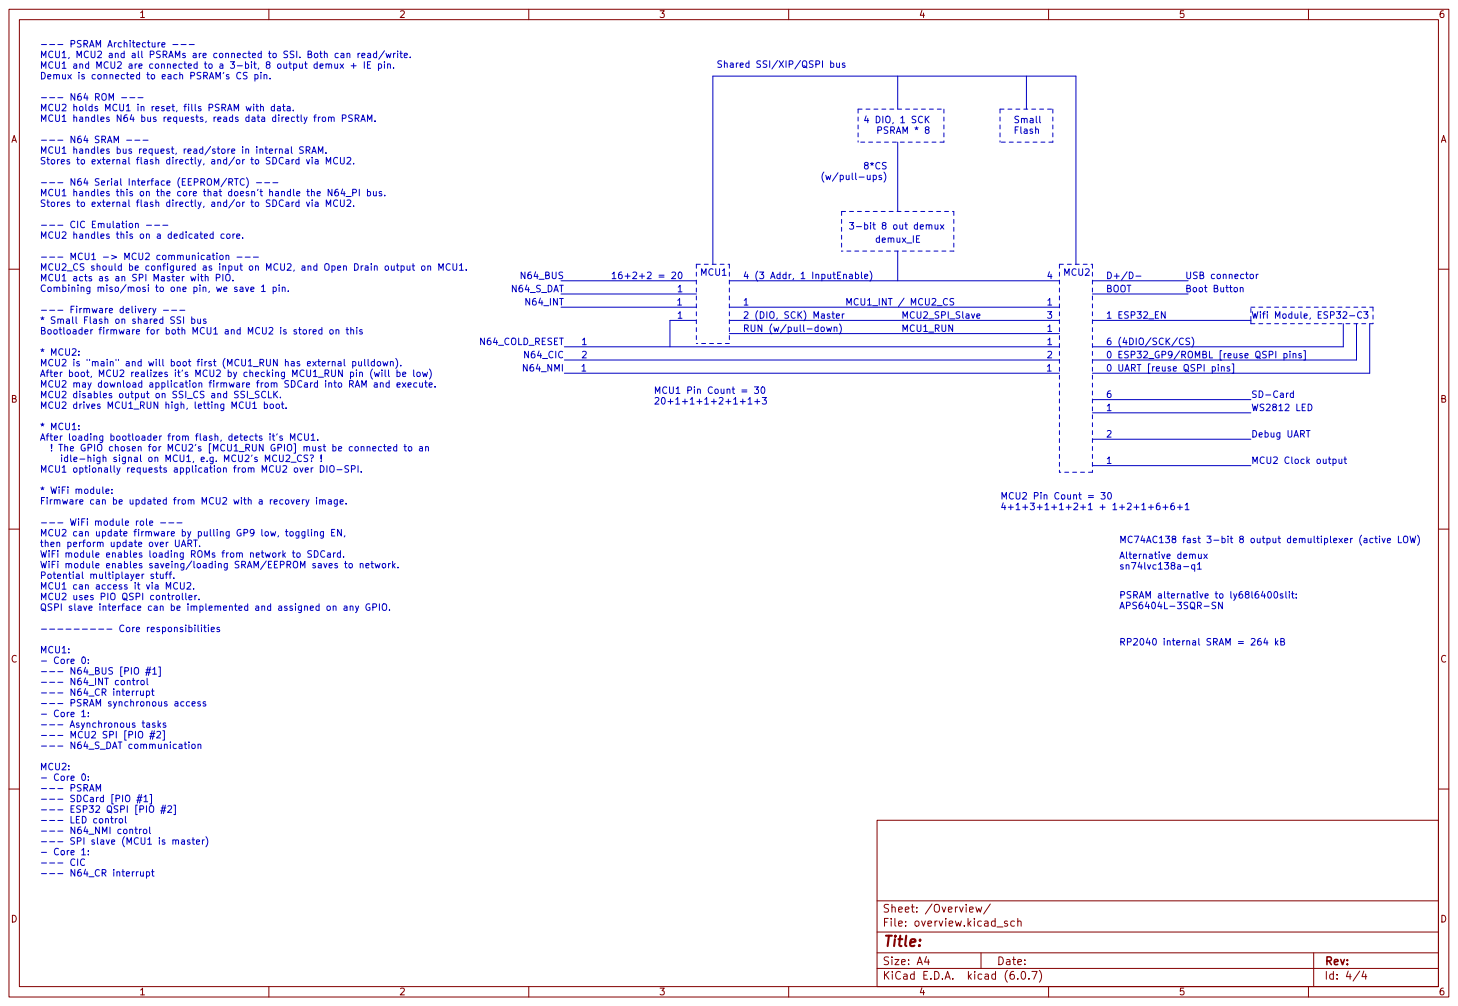
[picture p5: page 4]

--- PSRAM Architecture --- MCU1, MCU2 and all PSRAMs are connected to SSI. Both can read/write. MCU1 and MCU2 are connected to a 3-bit, 8 output demux + IE pin.

Demux is connected to each PSRAM's CS pin. --- N64 ROM --- MCU2 holds MCU1 in reset, fills PSRAM with data. MCU1 handles N64 bus requests, reads data directly from PSRAM. --- N64 SRAM --- MCU1 handles bus request, read/store in internal SRAM.

Stores to external flash directly, and/or to SDCard via MCU2.

--- N64 Serial Interface (EEPROM/RTC) --- MCU1 handles this on the core that doesn't handle the N64_PI bus. Stores to external flash directly, and/or to SDCard via MCU2. --- CIC Emulation --- MCU2 handles this on a dedicated core. --- MCU1 -> MCU2 communication --- MCU2_CS should be configured as input on MCU2, and Open Drain output on MCU1. MCU1 acts as an SPI Master with PIO. Combining miso/mosi to one pin, we save 1 pin.

0 ESP32_GP9/ROMBL [reuse QSPI pins] 1

--- Firmware delivery --- * Small Flash on shared SSI bus Bootloader firmware for both MCU1 and MCU2 is stored on this

0 UART [reuse QSPI pins] 1 ESP32_EN

* MCU2: MCU2 is "main" and will boot first (MCU1_RUN has external pulldown).

After boot, MCU2 realizes it's MCU2 by checking MCU1_RUN pin (will be low)
MCU2 may download application firmware from SDCard into RAM and execute.
MCU2 disables output on SSI_CS and SSI_SCLK.
MCU2 drives MCU1_RUN high, letting MCU1 boot. * MCU1: After loading bootloader from flash, detects it's MCU1.

! The GPIO chosen for MCU2's [MCU1_RUN GPIO] must be connected to an
idle-high signal on MCU1, e.g. MCU2's MCU2_CS? !
MCU1 optionally requests application from MCU2 over DIO-SPI. * WiFi module: Firmware can be updated from MCU2 with a recovery image. --- WiFi module role --- MCU2 can update firmware by pulling GP9 low, toggling EN,

then perform update over UART.
WiFi module enables loading ROMs from network to SDCard.
WiFi module enables saveing/loading SRAM/EEPROM saves to network.
Potential multiplayer stuff. MCU1 can access it via MCU2. MCU2 uses PIO QSPI controller. QSPI slave interface can be implemented and assigned on any GPIO.

PSRAM alternative to ly68l6400slit: APS6404L-3SQR-SN

--------- Core responsibilities MCU1: - Core 0: --- N64_BUS [PIO #1] --- N64_INT control --- N64_CR interrupt

--- MCU2 SPI [PIO #2] --- N64_S_DAT communication MCU2: - Core 0: --- PSRAM

--- SDCard [PIO #1]
--- ESP32 QSPI [PIO #2] --- LED control --- N64_NMI control --- SPI slave (MCU1 is master)

File: overview.kicad_sch Sheet: /Overview/
Id: 4/4 Title:

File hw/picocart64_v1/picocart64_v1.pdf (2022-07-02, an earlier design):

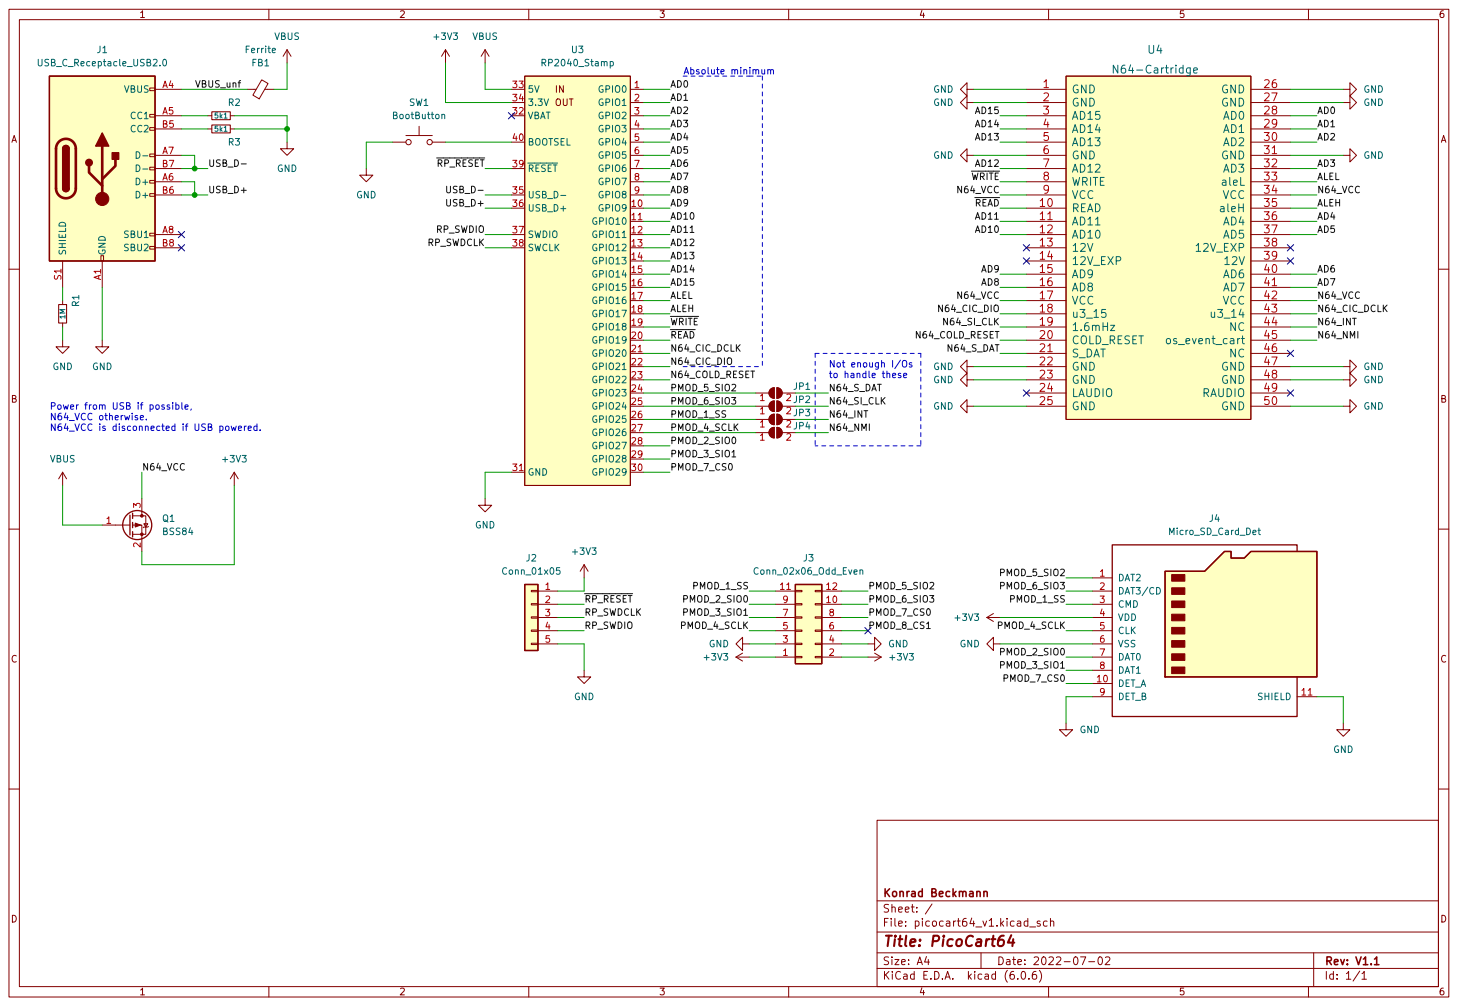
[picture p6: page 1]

Power from USB if possible, N64_VCC otherwise. N64_VCC is disconnected if USB powered.

File: picocart64_v1.kicad_sch Sheet: / Konrad Beckmann

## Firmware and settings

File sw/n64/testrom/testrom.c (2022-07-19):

/**
 * SPDX-License-Identifier: BSD-2-Clause
 *
 * Copyright (c) 2022 Konrad Beckmann <konrad.beckmann@gmail.com>
 * Copyright (c) 2022 Christopher Bonhage <me@christopherbonhage.com>
 *
 * Based on https://github.com/meeq/SaveTest-N64
 */

#include <string.h>
#include <stdint.h>
#include <libdragon.h>

#include "git_info.h"
#include "shell.h"

// picocart64_shared
#include "pc64_regs.h"
#include "pc64_rand.h"
#include "n64_defs.h"

typedef struct PI_regs_s {
	volatile void *ram_address;
	uint32_t pi_address;
	uint32_t read_length;
	uint32_t write_length;
} PI_regs_t;
static volatile PI_regs_t *const PI_regs = (PI_regs_t *) 0xA4600000;

// SRAM constants
#define SRAM_256KBIT_SIZE         0x00008000
#define SRAM_768KBIT_SIZE         0x00018000
#define SRAM_1MBIT_SIZE           0x00020000
#define SRAM_BANK_SIZE            SRAM_256KBIT_SIZE
#define SRAM_256KBIT_BANKS        1
#define SRAM_768KBIT_BANKS        3
#define SRAM_1MBIT_BANKS          4

static void verify_memory_range(uint32_t base, uint32_t offset, uint32_t len)
{
	uint32_t start = base | offset;
	uint32_t end = start + len - 1;

	switch (base) {
	case CART_DOM2_ADDR1_START:
		assert(start >= CART_DOM2_ADDR1_START);
		assert(start <= CART_DOM2_ADDR1_END);
		assert(end >= CART_DOM2_ADDR1_START);
		assert(end <= CART_DOM2_ADDR1_END);
		break;

	case CART_DOM1_ADDR1_START:
		assert(start >= CART_DOM1_ADDR1_START);
		assert(start <= CART_DOM1_ADDR1_END);
		assert(end >= CART_DOM1_ADDR1_START);
		assert(end <= CART_DOM1_ADDR1_END);
		break;

	case CART_DOM2_ADDR2_START:
		assert(start >= CART_DOM2_ADDR2_START);
		assert(start <= CART_DOM2_ADDR2_END);
		assert(end >= CART_DOM2_ADDR2_START);
		assert(end <= CART_DOM2_ADDR2_END);
		break;

	case CART_DOM1_ADDR2_START:
		assert(start >= CART_DOM1_ADDR2_START);
		assert(start <= CART_DOM1_ADDR2_END);
		assert(end >= CART_DOM1_ADDR2_START);
		assert(end <= CART_DOM1_ADDR2_END);
		break;

	case CART_DOM1_ADDR3_START:
		assert(start >= CART_DOM1_ADDR3_START);
		assert(start <= CART_DOM1_ADDR3_END);
		assert(end >= CART_DOM1_ADDR3_START);
		assert(end <= CART_DOM1_ADDR3_END);
		break;

	case PC64_BASE_ADDRESS_START:
		assert(start >= PC64_BASE_ADDRESS_START);
		assert(start <= PC64_BASE_ADDRESS_END);
		assert(end >= PC64_BASE_ADDRESS_START);
		assert(end <= PC64_BASE_ADDRESS_END);
		break;

	case PC64_RAND_ADDRESS_START:
		assert(start >= PC64_RAND_ADDRESS_START);
		assert(start <= PC64_RAND_ADDRESS_END);
		assert(end >= PC64_RAND_ADDRESS_START);
		assert(end <= PC64_RAND_ADDRESS_END);
		break;

	case PC64_CIBASE_ADDRESS_START:
		assert(start >= PC64_CIBASE_ADDRESS_START);
		assert(start <= PC64_CIBASE_ADDRESS_END);
		assert(end >= PC64_CIBASE_ADDRESS_START);
		assert(end <= PC64_CIBASE_ADDRESS_END);
		break;

	default:
		assert(!"Unsupported base");
	}
}

static void pi_read_raw(void *dest, uint32_t base, uint32_t offset, uint32_t len)
{
	assert(dest != NULL);
	verify_memory_range(base, offset, len);

	disable_interrupts();
	dma_wait();

	MEMORY_BARRIER();
	PI_regs->ram_address = UncachedAddr(dest);
	MEMORY_BARRIER();
	PI_regs->pi_address = offset | base;
	MEMORY_BARRIER();
	PI_regs->write_length = len - 1;
	MEMORY_BARRIER();

	enable_interrupts();
	dma_wait();
}

static void pi_write_raw(const void *src, uint32_t base, uint32_t offset, uint32_t len)
{
	assert(src != NULL);
	verify_memory_range(base, offset, len);

	disable_interrupts();
	dma_wait();

	MEMORY_BARRIER();
	PI_regs->ram_address = UncachedAddr(src);
	MEMORY_BARRIER();
	PI_regs->pi_address = offset | base;
	MEMORY_BARRIER();
	PI_regs->read_length = len - 1;
	MEMORY_BARRIER();

	enable_interrupts();
	dma_wait();
}

static void pi_write_u32(const uint32_t value, uint32_t base, uint32_t offset)
{
	uint32_t buf[] = { value };

	data_cache_hit_writeback_invalidate(buf, sizeof(buf));
	pi_write_raw(buf, base, offset, sizeof(buf));
}

static uint8_t __attribute__((aligned(16))) facit_buf[SRAM_1MBIT_SIZE];
static uint8_t __attribute__((aligned(16))) read_buf[SRAM_1MBIT_SIZE];
static char __attribute__((aligned(16))) write_buf[0x1000];

static void pc64_uart_write(const uint8_t * buf, uint32_t len)
{
	// 16-bit aligned
	assert((((uint32_t) buf) & 0x1) == 0);

	uint32_t len_aligned32 = (len + 3) & (-4);

	data_cache_hit_writeback_invalidate((uint8_t *) buf, len_aligned32);
	pi_write_raw(write_buf, PC64_BASE_ADDRESS_START, 0, len_aligned32);

	pi_write_u32(len, PC64_CIBASE_ADDRESS_START, PC64_REGISTER_UART_TX);
}

static void configure_sram(void)
{
	// PI registers
#define PI_BASE_REG          0x04600000
#define PI_STATUS_REG        (PI_BASE_REG+0x10)
#define	PI_STATUS_ERROR      0x04
#define PI_STATUS_IO_BUSY    0x02
#define PI_STATUS_DMA_BUSY   0x01

#define PI_BSD_DOM1_LAT_REG  (PI_BASE_REG+0x14)
#define PI_BSD_DOM1_PWD_REG  (PI_BASE_REG+0x18)
#define PI_BSD_DOM1_PGS_REG  (PI_BASE_REG+0x1C)
#define PI_BSD_DOM1_RLS_REG  (PI_BASE_REG+0x20)
#define PI_BSD_DOM2_LAT_REG  (PI_BASE_REG+0x24)
#define PI_BSD_DOM2_PWD_REG  (PI_BASE_REG+0x28)
#define PI_BSD_DOM2_PGS_REG  (PI_BASE_REG+0x2C)
#define PI_BSD_DOM2_RLS_REG  (PI_BASE_REG+0x30)

	// MIPS addresses
#define KSEG0 0x80000000
#define KSEG1 0xA0000000

	// Memory translation stuff
#define	PHYS_TO_K1(x)       ((uint32_t)(x)|KSEG1)
#define	IO_WRITE(addr,data) (*(volatile uint32_t *)PHYS_TO_K1(addr)=(uint32_t)(data))
#define	IO_READ(addr)       (*(volatile uint32_t *)PHYS_TO_K1(addr))

	// Initialize the PI
	IO_WRITE(PI_STATUS_REG, 3);

	// SDK default, 0x80371240
	//                  DCBBAA
	// AA = LAT
	// BB = PWD
	//  C = PGS
	//  D = RLS
	//
	// 1 cycle = 1/62.5 MHz = 16ns
	// Time = (register+1)*16ns
	// LAT = tL = 0x40 = 65 cycles
	// PWM = tP = 0x12 = 19 cycles
	// PGS      = 0x07 = 512 bytes page size
	// RLS = tR = 0x03 = 4 cycles

#if 0
	IO_WRITE(PI_BSD_DOM1_LAT_REG, 0x40);
	IO_WRITE(PI_BSD_DOM1_PWD_REG, 0x12);
	IO_WRITE(PI_BSD_DOM1_PGS_REG, 0x07);
	IO_WRITE(PI_BSD_DOM1_RLS_REG, 0x03);

	IO_WRITE(PI_BSD_DOM2_LAT_REG, 0x40);
	IO_WRITE(PI_BSD_DOM2_PWD_REG, 0x12);
	IO_WRITE(PI_BSD_DOM2_PGS_REG, 0x07);
	IO_WRITE(PI_BSD_DOM2_RLS_REG, 0x03);

#else
	// Fast SRAM access (should match SDK values)
	IO_WRITE(PI_BSD_DOM2_LAT_REG, 0x40);
	IO_WRITE(PI_BSD_DOM2_PWD_REG, 0x0C);
	IO_WRITE(PI_BSD_DOM2_PGS_REG, 0x07);
	IO_WRITE(PI_BSD_DOM2_RLS_REG, 0x03);
#endif
}

int main(void)
{
	uint32_t *facit_buf32 = (uint32_t *) facit_buf;
	uint32_t *read_buf32 = (uint32_t *) read_buf;
	uint16_t *read_buf16 = (uint16_t *) read_buf;

	configure_sram();

	display_init(RESOLUTION_320x240, DEPTH_32_BPP, 2, GAMMA_NONE, ANTIALIAS_RESAMPLE);
	console_init();
	// debug_init_isviewer();

	printf("PicoCart64 Test ROM (git rev %08X)\n\n", GIT_REV);

	///////////////////////////////////////////////////////////////////////////

	// Verify PicoCart64 Magic
	data_cache_hit_writeback_invalidate(read_buf, sizeof(read_buf));
	pi_read_raw(read_buf, PC64_CIBASE_ADDRESS_START, PC64_REGISTER_MAGIC, sizeof(uint32_t));
	if (read_buf32[0] == PC64_MAGIC) {
		printf("[ OK ] MAGIC = 0x%08lX.\n", read_buf32[0]);
	} else {
		printf("[FAIL] MAGIC = 0x%08lX.\n", read_buf32[0]);
	}

	///////////////////////////////////////////////////////////////////////////

	// Print Hello from the N64
	strcpy(write_buf, "Hello from the N64!\r\n");
	pc64_uart_write((const uint8_t *)write_buf, strlen(write_buf));
	printf("[ -- ] Wrote hello over UART.\n");

	///////////////////////////////////////////////////////////////////////////

	// Initialize a random sequence
	pc64_rand_seed(0);
	data_cache_hit_writeback_invalidate(facit_buf, sizeof(facit_buf));
	for (int i = 0; i < sizeof(facit_buf) / sizeof(uint32_t); i++) {
		facit_buf32[i] = pc64_rand32();
	}

	// Read back 1Mbit of SRAM
	data_cache_hit_writeback_invalidate(read_buf, sizeof(read_buf));
	pi_read_raw(read_buf, CART_DOM2_ADDR2_START, 0, sizeof(read_buf));

	// Compare SRAM with the facit
	if (memcmp(facit_buf, read_buf, sizeof(read_buf)) != 0) {
		printf("[FAIL] SRAM was not backed up properly.\n");

		for (int i = 0; i < sizeof(facit_buf) / sizeof(uint32_t); i++) {
			if (facit_buf32[i] != read_buf[i]) {
				printf("       Error @%d: facit %08lX != sram %08lX\n", i, facit_buf32[i], read_buf32[i]);
				break;
			}
		}
	} else {
		printf("[ OK ] SRAM was backed up properly.\n");
	}

	///////////////////////////////////////////////////////////////////////////

	// Write 1Mbit of SRAM
	data_cache_hit_writeback_invalidate(facit_buf, sizeof(facit_buf));
	pi_write_raw(facit_buf, CART_DOM2_ADDR2_START, 0, sizeof(facit_buf));

	printf("[ -- ] Wrote test pattern to SRAM.\n");

	// Read it back and verify
	data_cache_hit_writeback_invalidate(read_buf, sizeof(read_buf));
	pi_read_raw(read_buf, CART_DOM2_ADDR2_START, 0, sizeof(read_buf));

	// Compare SRAM with the facit
	if (memcmp(facit_buf, read_buf, sizeof(read_buf)) != 0) {
		printf("[FAIL] SRAM (volatile) did not verify correctly.\n");

		for (int i = 0; i < sizeof(facit_buf) / sizeof(uint32_t); i++) {
			if (facit_buf32[i] != read_buf[i]) {
				printf("       Error @%d: facit %08lX != sram %08lX\n", i, facit_buf32[i], read_buf32[i]);
				break;
			}
		}
	} else {
		printf("[ OK ] (volatile) SRAM verified correctly.\n");
	}

	///////////////////////////////////////////////////////////////////////////

	// Stress test: Read pseudo-random numbers from PicoCart64 RAND address space
	// Reset random seed
	pi_write_u32(0, PC64_CIBASE_ADDRESS_START, PC64_REGISTER_RAND_SEED);
	pc64_rand_seed(0);

	// Compare buffer with RNG
	printf("[ -- ] RNG Test: ");
	bool rng_ok = true;
	for (int j = 0; j < 64 && rng_ok; j++) {
		// Read back 1Mbit of RAND values
		data_cache_hit_writeback_invalidate(read_buf, sizeof(read_buf));
		pi_read_raw(read_buf, PC64_RAND_ADDRESS_START, 0, sizeof(read_buf));
		printf(".");
		fflush(stdout);

		for (int i = 0; i < sizeof(read_buf) / sizeof(uint16_t); i++) {
			uint16_t value = pc64_rand16();

			if (value != read_buf16[i]) {
				printf("\n       Error @%d: ours %04X != theirs %04X", i, value, read_buf16[i]);
				rng_ok = false;
				break;
			}
		}
	}

	if (rng_ok) {
		printf("\n[ OK ] Random stress test verified correctly.\n");
	} else {
		printf("\n[FAIL] Random stress test failed.\n");
	}

	///////////////////////////////////////////////////////////////////////////

	// Read 1Mbit of 64DD IPL ROM
	data_cache_hit_writeback_invalidate(read_buf, sizeof(read_buf));
	pi_read_raw(read_buf, CART_DOM1_ADDR1_START, 0, sizeof(read_buf));
	printf("[ -- ] Read from the N64DD address space.\n");

	// Verify the PicoCart64 Magic *again*
	// This is done to ensure that the PicoCart64 is still alive and well,
	// and hasn't crashed or locked itself up.
	data_cache_hit_writeback_invalidate(read_buf, sizeof(read_buf));
	pi_read_raw(read_buf, PC64_CIBASE_ADDRESS_START, PC64_REGISTER_MAGIC, sizeof(uint32_t));
	if (read_buf32[0] == PC64_MAGIC) {
		printf("[ OK ] (second time) MAGIC = 0x%08lX.\n", read_buf32[0]);
	} else {
		printf("[FAIL] (second time) MAGIC = 0x%08lX.\n", read_buf32[0]);
		printf("       PicoCart64 might stall now and require a power cycle.\n");
	}

	console_render();

	/* Start the shell if the user presses start */
	printf("\n\nPress START to continue to the shell...\n");
	controller_init();
	while (true) {
		controller_scan();
		struct controller_data keys = get_keys_pressed();
		if (keys.c[0].start) {
			printf("Start pressed.\n");
			break;
		}
	}

	start_shell();
}

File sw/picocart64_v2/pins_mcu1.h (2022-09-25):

/**
 * SPDX-License-Identifier: BSD-2-Clause
 *
 * Copyright (c) 2022 Konrad Beckmann
 */

#pragma once

#define PIN_N64_AD0         ( 0)
#define PIN_N64_AD1         ( 1)
#define PIN_N64_AD2         ( 2)
#define PIN_N64_AD3         ( 3)
#define PIN_N64_AD4         ( 4)
#define PIN_N64_AD5         ( 5)
#define PIN_N64_AD6         ( 6)
#define PIN_N64_AD7         ( 7)
#define PIN_N64_AD8         ( 8)
#define PIN_N64_AD9         ( 9)
#define PIN_N64_AD10        (10)
#define PIN_N64_AD11        (11)
#define PIN_N64_AD12        (12)
#define PIN_N64_AD13        (13)
#define PIN_N64_AD14        (14)
#define PIN_N64_AD15        (15)
#define PIN_N64_ALEL        (16)
#define PIN_N64_ALEH        (17)
#define PIN_N64_WRITE       (18)
#define PIN_N64_READ        (19)
#define PIN_N64_COLD_RESET  (20)
#define PIN_N64_SI_DAT      (21)
#define PIN_N64_INT1        (22)
#define PIN_DEMUX_A0        (23)
#define PIN_DEMUX_A1        (24)
#define PIN_DEMUX_A2        (25)
#define PIN_DEMUX_IE        (26)
#define PIN_MCU2_SCK        (27)
#define PIN_MCU2_CS         (28)
#define PIN_MCU2_DIO        (29)

#define DEBUG_UART uart0
#define DEBUG_UART_BAUD_RATE 115200
#define DEBUG_UART_TX_PIN (PIN_MCU2_CS)
#define DEBUG_UART_RX_PIN (-1)

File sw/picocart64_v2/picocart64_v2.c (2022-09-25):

/**
 * SPDX-License-Identifier: BSD-2-Clause
 *
 * Copyright (c) 2022 Konrad Beckmann
 */

#include <stdio.h>

#include "pico/stdlib.h"
#include "hardware/structs/ssi.h"
#include "hardware/structs/ioqspi.h"

#include "FreeRTOS.h"
#include "task.h"

#include "mcu1.h"
#include "mcu2.h"
#include "qspi_helper.h"

#define PIN_ID    (26)
#define MCU1_ID   ( 1)
#define MCU2_ID   ( 2)

/*
 * PicoCart64 v2 is connected in the following way:
 * MCU1        - FLASH (+PSRAM) - MCU2
 * MCU1.GPIO26                  - 10k Pull Down
 * MCU2.GPIO26                  - 10k Pull Up
 * MCU2.GPIO19 - MCU1.RUN       - 10k Pull Down
 *
 * MCU2 boots first, copies program from flash to RAM and executes.
 * MCU2 reads GPIO26. If HIGH: we are MCU2.
 * MCU2 sets QSPI OutputEnable override to Disabled.
 * MCU2 drives GPIO19 HIGH, letting MCU1 boot.
 * MCU1 boots, copies program from flash to RAM and executes.
 * MCU1 reads GPIO26. If LOW: we are MCU1.
 * MCU1 sets QSPI OutputEnable override to Disabled.
 * Done.
 *
 */

// FreeRTOS boilerplate
void vApplicationGetTimerTaskMemory(StaticTask_t ** ppxTimerTaskTCBBuffer, StackType_t ** ppxTimerTaskStackBuffer, uint32_t * pulTimerTaskStackSize)
{
	static StaticTask_t xTimerTaskTCB;
	static StackType_t uxTimerTaskStack[configTIMER_TASK_STACK_DEPTH];

	*ppxTimerTaskTCBBuffer = &xTimerTaskTCB;
	*ppxTimerTaskStackBuffer = uxTimerTaskStack;
	*pulTimerTaskStackSize = configTIMER_TASK_STACK_DEPTH;
}

int main(void)
{
	// On MCU1, PIN_ID is pulled low externally.
	// On MCU2, PIN_ID is pulled high externally and connected to MCU1.RUN.
	gpio_init(PIN_ID);
	gpio_set_dir(PIN_ID, GPIO_IN);
	gpio_disable_pulls(PIN_ID);

	// mcu_id will be 1 for MCU1, and 2 for MCU2.
	int mcu_id = gpio_get(PIN_ID) + 1;

	// Turn off SSI
	ssi_hw->ssienr = 0;

	// Disable output enable (OE) on all QSPI IO pins
	qspi_oeover_disable();

	if (mcu_id == MCU1_ID) {
		mcu1_main();
	} else if (mcu_id == MCU2_ID) {
		// It's up to MCU2 to let MCU1 boot
		mcu2_main();
	}
	// Never reached
	while (true) {
	}

	return 0;
}

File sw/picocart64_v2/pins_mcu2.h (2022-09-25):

/**
 * SPDX-License-Identifier: BSD-2-Clause
 *
 * Copyright (c) 2022 Konrad Beckmann
 */

#pragma once

#define PIN_UART0_TX          ( 0)
#define PIN_UART0_RX          ( 1)
#define PIN_SD_CLK            ( 2)
#define PIN_SD_CMD            ( 3)
#define PIN_SD_DAT0_UART1_TX  ( 4)
#define PIN_SD_DAT1_UART1_RX  ( 5)
#define PIN_SD_DAT2           ( 6)
#define PIN_SD_DAT3           ( 7)
#define PIN_ESP32_D0          ( 8)
#define PIN_ESP32_D1          ( 9)
#define PIN_ESP32_D2          (10)
#define PIN_ESP32_D3          (11)
#define PIN_ESP32_CS          (12)
#define PIN_ESP32_SCK         (13)
#define PIN_ESP32_EN          (14)
#define PIN_DEMUX_A0          (15)
#define PIN_DEMUX_A1          (16)
#define PIN_DEMUX_A2          (17)
#define PIN_DEMUX_IE          (18)
#define PIN_MCU1_RUN          (19)
#define PIN_LED               (20)
#define PIN_MCU2_GPIO21       (21)
#define PIN_N64_COLD_RESET    (22)
#define PIN_N64_NMI           (23)
#define PIN_CIC_DIO           (24)
#define PIN_CIC_DCLK          (25)
#define PIN_SPI1_SCK          (26)
#define PIN_SPI1_TX           (27)
#define PIN_SPI1_RX           (28)
#define PIN_SPI1_CS           (29)

#define DEBUG_UART uart0
#define DEBUG_UART_BAUD_RATE 115200
#define DEBUG_UART_TX_PIN (PIN_UART0_TX)
#define DEBUG_UART_RX_PIN (PIN_UART0_RX)

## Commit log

2022-06-17 Everything routed
    [picocart64_v1.kicad_pcb, picocart64_v1.kicad_sch]
2022-06-19 Almost there
    - UART on pin 28
    - Improved ringbuf
    - Read ROM from flash
    The latency doesn't seem too bad for homebrew, just need to get the CIC
    chip working
    [cic.c, cic_test.c]
2022-06-20 cic: Add support for power cycling the N64
2022-06-20 Fix typo in profiling results
    [cic_test.c]
2022-06-21 hw: checkpoint
    [picocart64_v1.kicad_pcb, picocart64_v1.kicad_sch]
2022-06-21 hw: PicoCart64 V1.0
    First exploratory revision
    [picocart64_v1.kicad_pcb, picocart64_v1.kicad_sch]
2022-06-21 hw: Gerbers for PicoCart64 V1.0
    [picocart64_v1-B_Cu.gbl, picocart64_v1-B_Mask.gbs, picocart64_v1-B_Silkscreen.gbo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]
2022-06-22 Add openocd config for 16MB flash
    [rp2040-16MB.cfg]
2022-06-25 hw: Fork picocart64_v1_lite
    [picocart64_v1_lite.kicad_pcb, picocart64_v1_lite.kicad_sch]
2022-06-26 hw: Add PicoCart64-lite v1.0
    [picocart64_v1_lite-B_Cu.gbl, picocart64_v1_lite-B_Mask.gbs, picocart64_v1_lite-B_Silkscreen.gbo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]
2022-06-26 hw: PicoCart-lite v1.1
    - Improved power routing
    [picocart64_v1_lite-B_Cu.gbl, picocart64_v1_lite-B_Mask.gbs, picocart64_v1_lite-B_Silkscreen.gbo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]
2022-06-29 hw: PicoCart64-lite v1.2
    - Improved routing a lot, removed many vias
    - Added more ground stitching vias
    - Functionally equivalent to v1.1 and v1.0
    [picocart64_v1_lite-B_Cu.gbl, picocart64_v1_lite-B_Mask.gbs, picocart64_v1_lite-B_Silkscreen.gbo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]
2022-06-30 sw: Map N64_READ pin to gpio19 to match PCBs
2022-07-02 hw: PicoCart64 V1.1
    - KiCad project files
    - Gerbers
    - PDF
    - Changelog since V1.0 + errata
    [picocart64_v1-B_Cu.gbl, picocart64_v1-B_Mask.gbs, picocart64_v1-B_Silkscreen.gbo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]
2022-07-04 sw: Fix SRAM support
    Both the contiguous and banked SRAM tests from https://github.com/meeq/SaveTest-N64 pass.
    This can probably be optimized further.
    Closes #12
    [picocart64.c]
2022-07-05 sw: Add persistent SRAM support
    During boot, Core1 will load the SRAM contents from flash into RAM.
    Core1 keeps track of when N64_CR is going low and
    pokes Core0 about this with an interrupt. This could be solved
    with a GPIO interrupt too I suppose.
    The interrupt handler will commit the SRAM contents to
    the external flash when this happens. This is done from
    IRQ because the main loop is stuck waiting for PIO data.
    Closes #13
    [cic.c, picocart64.c]
2022-07-05 sw: Improve PI handling speed
    Rewrote the mainloop logic to prefetch before the read/write command
    has been received.
    Added a priority-ordered if-statement chain to check for which
    address space to serve first.
    Closes #16
2022-07-05 sw: Change PIO in shift direction to remove swap16()
    This removes a few cycles in the CPU. Not really a measurable gain.
    [picocart64.c]
2022-07-05 sw: Swap responsibilities of cores
    core0 is now handling the cic emulation (eventually RTOS as well)
    core1 handles the n64_pi
    [cic.c, n64_pi.c, picocart64.c]
2022-07-06 sw: Print compression stats
2022-07-07 sw: compression: Fix bug and make chunk size configurable
    The chunk index was not updated properly earlier, leading to incorrect indexes after a chunk was found.
    The compression code is faster now as well.
    [n64_pi.c]
2022-07-13 sw: Implement asynchronous UART TX
    This is a simple interrupt based asynchronous UART TX module that works as a drop-in replacement for stdio_uart.
    It uses a ringbuffer to queue up data that is to be transmitted, and starts by sending one byte.
    When the byte has been transmitted, an interrupt is fired, and the next one is sent, until the tail of the ringbuffer has caught up with the head.
    [n64_pi.c, picocart64.c, stdio_async_uart.c]
2022-07-13 sw: Initial UART print support from the N64
    From the N64 it is now possible to print directly to the
    UART on the PicoCart64.
2022-07-14 sw: Add missing break
    [n64_pi.c]
2022-07-15 sw: Rewrite missing region help message
    [cic.c]
2022-07-15 sw: Print git revision in testrom
2022-07-15 sw: Print git revision in PicoCart64 boot message
2022-07-18 ci: Add indentation script
    Run `./sw/scripts/indent.sh --cleanup` to quickly fix indentation and
    remove backup files (skip --cleanup otherwise).
    The GitHub action will create a commit with proper indentation if a commit introduces code with improper indentation.
    [cic.c, n64_pi.c, picocart64.c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]
2022-07-21 sw: Add simple way to print unhandled addresses
2022-07-21 sw: Use correct PIO offset in jump instruction execution
    [n64_pi.c]
2022-07-24 sw: dualpico: Fix indentation
    [dualpico.c]
2022-07-28 ROM rework (#41)
    * Move ROM to a fixed offset in flash
    * make size configurable with FLASH_SIZE var
    * Also chunk uncompressed ROMs, so the same code can be used for both types.
    * update README for changes
    * fix MAPPING_TABLE_LEN definition
    * fixup: fix CMake typo...
    * Fix minor things from review
    [n64_pi.c, picocart64.c, rom_vars.h]
2022-08-14 hw: PicoCart64 v2.0
    [board.kicad_sch, n64_cart.kicad_sch, overview.kicad_sch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]
2022-08-14 hw: PicoCart64-lite v1.3
    [picocart64_v1_lite-B_Cu.gbl, picocart64_v1_lite-B_Mask.gbs, picocart64_v1_lite-B_Silkscreen.gbo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]
2022-08-15 hw: PicoCart v2: Improve power routing for VBus'
    [picocart64_v2.kicad_pcb, picocart64_v2.kicad_sch]
2022-08-15 add JLCPCB extension DB
    [picocart64_v2.kicad_pcb, rotations.csv]
2022-08-15 hw: Remove accidentally added file
    [n64_cart.kicad_sch]
2022-08-16 hw: picocart64_v2: Added alternative LED and pin 1 markings
    [board.kicad_sch, picocart64_v2.kicad_pcb, picocart64_v2.kicad_sch]
2022-08-16 hw: picocart64_v2: Increased spacing between traces
    [picocart64_v2.kicad_pcb]
2022-08-16 hw: update JLCPCB files for new LED (#45)
    Add LCSC part number to BOM
    fix rotation on LED
    Exclude D1 LED from POS by default
    [picocart64_v2.kicad_pcb, rotations.csv]
